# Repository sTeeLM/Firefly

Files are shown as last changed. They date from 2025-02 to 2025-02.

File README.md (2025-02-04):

# 微型长电池寿命多功能户外应急灯

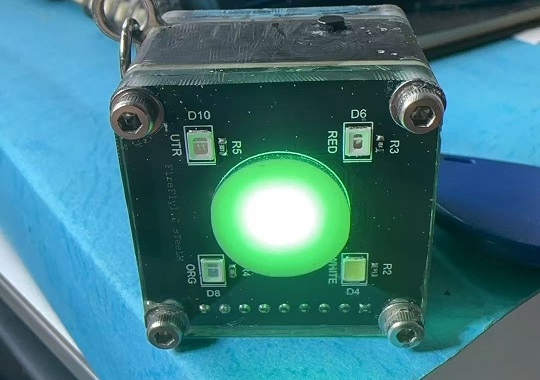
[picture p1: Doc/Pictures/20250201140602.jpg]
前脸
 

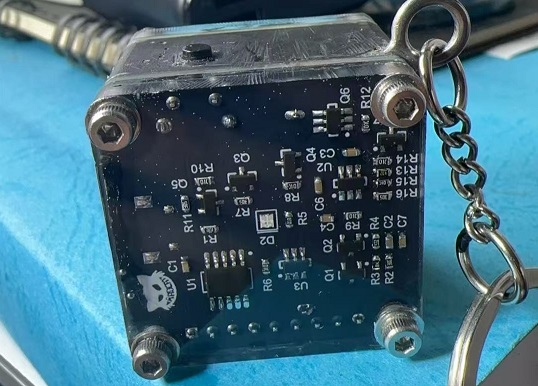
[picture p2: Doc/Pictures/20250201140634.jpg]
后脸


## 有啥用：
   无意间看到淘宝上有类似的户外应急灯，功能比较单一（只有一个荧光灯），还卖的不便宜，正好入手了一些超小号的8引脚单片机，放着也没啥用
   
   平时可以挂在钥匙链上，夜间紧急停车的时候，可以开着频闪放在车后当警示，也能当手电用，登山的时候挂包上，开着荧光节能模式，一闪一闪像萤火虫，可以防止后面队友跟丢（或者是自己丢了方便被找到）。

## 功能：
1. 长电池寿命：长亮模式2小时，5秒频闪模式24小时，长效模式（15秒频闪）3天，关机下漏电nA级别，可长期保存
2. 多种功能：
   * 长效荧光灯:用紫外光周期激发高亮荧光粉，从而以极低的功耗获得不错的照明效果，支持常亮、5秒、15秒三种模式
   * 白光手电：常亮、1秒频闪、5秒频闪三种模式
   * 橙色雾灯：常亮、1秒频闪、5秒频闪三种模式
   * 红色警示灯：常亮、1秒频闪、5秒频闪三种模式
   * 紫外验钞灯：常亮
   * 防误触开机：长按+4次短按开机，误触会有频闪提示，防止装兜里不小心打开
3. 户外设计：
   * 全密封灌胶防尘防水

## 设计细节：
1. 大小35mm x 35mm x 30mm，电池使用LR2447纽扣电池，标称容量190mAh，放电电流100mA，一次只能至多点亮一个LED(60mA)，更多的话需要考虑另一颗电池并联
2. 比较经典的TP4056充电+PW5410B电荷泵升降压到3.3V+USB、电池切换的设计，只是加了一个双MOS管的防止电池向TP4056漏电的设计，从而延长了保存时间
3. 8引脚的STC8G17A单片机+TCA9534A扩展IO，很皮实，而且自带低电压检测功能，国产低端芯片很强大
4. 灌注了两次环氧树脂胶+各种打磨，需要手工比较多，量产的话可以考虑3D打印外壳

# Miniature Multifunctional Outdoor Emergency Light with Long Battery Life
## What It's Used For
I happened to notice some similar outdoor emergency lights on Taobao. They have rather limited functions (only a fluorescent lamp) and are priced quite high. Coincidentally, I had acquired some ultra small 8 pin microcontrollers, which were just sitting idle, so I decided to make one on my own.

Normally, it can be attached to a keychain. In case of an emergency stop at night, it can be turned on with a strobe function and placed behind the car as a warning. It can also serve as a flashlight. When going hiking, hanging it on the backpack and activating the fluorescent energy saving mode, it will flash like a firefly, preventing fellow hikers from losing track of each other (or making it easier for oneself to be located if lost).
## Functions
1. Long Battery Life
* Continuous on mode: 2 hours.
* 5 second strobe mode: 24 hours.
* Extended duration mode (15 second strobe): 3 days.
* Battery leakage is in the nA range when powered off, enabling long term storage.
2. Multiple Functions
* Long lasting Fluorescent Lamp: High brightness phosphors are excited periodically by ultraviolet light, achieving a good lighting effect with extremely low power consumption. It supports three modes: continuous on, 5 second strobe, and 15 second strobe.
* White light Flashlight: Offers three modes: continuous on, 1 second strobe, and 5 second strobe.
* Orange Fog Lamp: Features three modes: continuous on, 1 second strobe, and 5 second strobe.
* Red Warning Light: Has three modes: continuous on, 1 second strobe, and 5 second strobe.
* Anti accidental Startup: It requires a long press followed by four short presses to start. In case of accidental touches, a strobe indication will be given to prevent accidental activation when in the pocket.
3. Outdoor oriented Design
* Fully sealed and potted for dust proof and waterproof performance.
## Design Details
1. The dimensions are 35mm * 35mm * 30mm. It uses an LR2477 button cell battery with a nominal capacity of 190mAh and a discharge current of 100mA. 2. Only one LED (60mA) can be illuminated at a time. If more LEDs need to be lit, parallel connection with another battery should be considered.
2. It adopts a classic design of TP4056 charging, PW5410B charge pump for buck boost to 3.3V, and USB battery switching. Additionally, a dual MOSFET design is added to prevent the battery from leaking current to TP4056, thus prolonging the storage time.
3. An 8 pin STC8G17A microcontroller combined with a TCA9534A for IO expansion is used. These components are robust and come with a built in low voltage detection function. Domestic low end chips prove to be quite powerful.
4. It is potted with epoxy resin glue twice and requires a fair amount of manual work such as various polishing processes. For mass production, a 3D printed shell can be considered.

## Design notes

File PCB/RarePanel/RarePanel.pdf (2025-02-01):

Line # | Name | Description | Designator | Value | Quantity
| | Capacitor | C1 | 104 | 1
| | Capacitor | C2, C7 | 106 | 2
| | Capacitor | C3, C4, C6 | 225 | 3
| 16V | Polarized Capacitor (Radial) | C5 | 100uF | 1
| USB-Micro | USB-Micro | CON1 | | 1
| 1N4148 | Default Diode | D1, D4, D5 | | 3
| RED_GR EEN_LED | RED_GREEN_L ED | D2 | | 1
| 1N4007, T7 | Default Diode | D3 | | 1
| Header 9 | Header, 9-Pin | P1 | | 1
| AO3401, A19T | P-Channel Power MOSFET | Q1, Q3, Q4 | | 3
| S8050,J3 Y | NPN Bipolar Transistor | Q2, Q7 | | 2
| AO3400, A09T | N-Channel Power MOSFET | Q5 | | 1
| AO6801 | AO6801 | Q6 | | 1
| | Resistor | R1 | 300R | 1
| | Resistor | R2 | 20K | 1
| | Resistor | R3, R6, R8, R9, R10, R12, R14, R15 | 10K | 8
| | Resistor | R4, R13 | 4.7K | 2
| | Resistor | R5 | 1K | 1
| | Resistor | R7, R11, R16 | 3M | 3
| Key | Single-Pole, Single-Throw Switch | S1 | | 1
| CH340K | CH340K | U1 | | 1
| PW5410 B | PW5410B | U2 | | 1
| JL4057A | JA4057A | U3 | | 1
| CR2447 | CR2447 | U4 | | 1

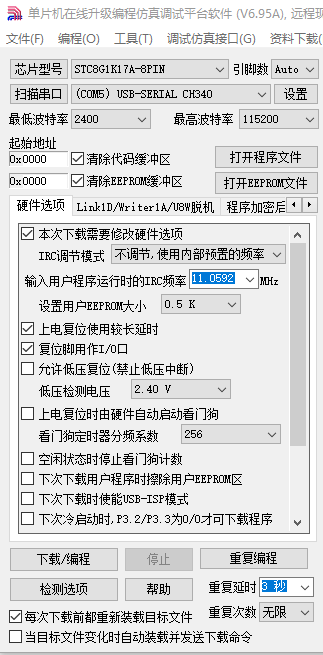
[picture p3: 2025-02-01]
Tools/config.png

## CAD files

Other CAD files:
Shell/A3面板.dwg
Shell/A3背板.dwg

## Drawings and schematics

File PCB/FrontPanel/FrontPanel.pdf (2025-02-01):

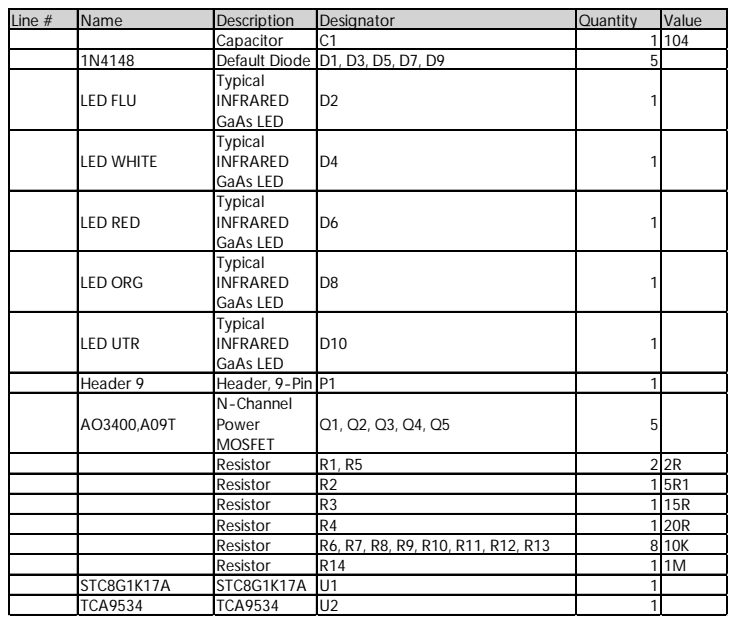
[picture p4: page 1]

Line # | Name | Description | Designator | Quantity | Value

Capacitor | C1 | 1 | 104

1N4148 | Default Diode | D1, D3, D5, D7, D9 | 5
LED FLU | Typical INFRARED GaAs LED | D2 | 1

LED WHITE | Typical INFRARED GaAs LED | D4 | 1

LED RED | Typical INFRARED GaAs LED | D6 | 1

LED ORG | Typical INFRARED GaAs LED | D8 | 1

LED UTR | Typical INFRARED GaAs LED | D10 | 1

Header 9 | Header, 9-Pin | P1 | 1
AO3400,A09T | N-Channel Power MOSFET | Q1, Q2, Q3, Q4, Q5 | 5

Resistor | R1, R5 | 2 2R
Resistor | R2 | 1 | 5R1
Resistor | R3 | 1 | 15R
Resistor | R4 | 1 | 20R
Resistor | R6, R7, R8, R9, R10, R11, R12, R13 | 8 10K
Resistor | R14 | 1 | 1M

STC8G1K17A | STC8G1K17A | U1 | 1
TCA9534 | TCA9534 | U2 | 1

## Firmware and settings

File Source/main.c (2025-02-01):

#include <STC8G.H>

#include "debug.h"
#include "gpio.h"
#include "power.h"
#include "com.h"
#include "delay.h"
#include "task.h"
#include "clock.h"
#include "power.h"
#include "button.h"
#include "int_hub.h"
#include "tdc.h"
#include "led.h"
#include "sm.h"
#include "task.h"

#define START_WAIT_JIFF 8

void main(void)
{
  uint32_t start_jiff;
  uint8_t  button_cnt;
  uint8_t  power_on = 0;
  
  EA = 1; 
  
  debug_initialize();
  gpio_initialize();
  com_initialize();
  power_initialize();
  
  gpio_enable_hub(1);
  
  power_set_enable(1);
  
  //如果插着USB开机，打开串口
  if(power_adapter_on()) {
    gpio_enable_serial(1);
    debug_onoff(1);
  }
  
  int_hub_initilize(); 
 
  clock_initialize();
  button_initialize();
  
  /* 使能其他外设 */
  tdc_initilize();
  led_initialize();
  
  task_initialize();
  sm_initialize(0);
  
  while(key_mod_pressed());
  
  /* 如果没有插充电器，运行防止误触碰逻辑 */
  
  if(!power_adapter_on()) { 
    start_jiff  = clock_get_now_jiff();
    button_cnt = button_get_down_cnt();
    
    while(clock_diff_now_jiff(start_jiff) <= START_WAIT_JIFF) {
      if(task_test(EV_EX_INT)) {
        int_hub_proc(EV_EX_INT);
        task_clr(EV_EX_INT);
      }
      if(button_cnt != button_get_down_cnt()) {
        start_jiff  = clock_get_now_jiff();
        button_cnt = button_get_down_cnt();
      }
      if(button_cnt >= 3) {
        sm_initialize(1);
        break;
      }
    }
  } else {
    CDBG("power_adapter_on\n"); 
  }
  
  led_power_enable(1);
  
  while(1) {
    task_run();
  }
}

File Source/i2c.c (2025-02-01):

#include <intrins.h>
#include <stdint.h>
#include "i2c.h"
#include "debug.h"
#include "delay.h"
#include "gpio.h"



void I2C_Delay()
{
  _nop_();
  _nop_();
  _nop_();
  _nop_();
}

void I2C_Init()
{
 I2C_SCL = 1;
 I2C_Delay();
 I2C_SDA = 1;
 I2C_Delay();
}


void I2C_Start()
{
  I2C_SDA = 1;
  I2C_Delay();
  I2C_SCL = 1;
  I2C_Delay();
  I2C_SDA = 0;
  I2C_Delay();
  I2C_SCL = 0;
  I2C_Delay();
}

void I2C_Stop()
{
  I2C_SDA = 0;
  I2C_Delay();
  I2C_SCL = 1;
  I2C_Delay();
  I2C_SDA = 1;
  I2C_Delay();
  I2C_Delay();
  I2C_Delay();
  I2C_Delay();
	delay_ms(5);
}



void I2C_Write(uint8_t dat)
{

  uint8_t t = 8;
  do
  {
     I2C_SDA = (bit)(dat & 0x80);
     dat <<= 1;
     I2C_SCL = 1;
     I2C_Delay();
     I2C_SCL = 0;
     I2C_Delay();
  } while ( --t != 0 );
}

uint8_t I2C_Read()
{
  char dat = 0;
  uint8_t t = 8;
  I2C_SDA = 1; //在读取数据之前，要把SDA拉高
  do
  {
     I2C_SCL = 1;
     I2C_Delay();
     dat <<= 1;
     if ( I2C_SDA ) dat |= 0x01;
     I2C_SCL = 0;
     I2C_Delay();
  } while ( --t != 0 );
  return dat;
}



bit I2C_GetAck()
{
  bit ack;
  I2C_SDA = 1;
  I2C_Delay();
  I2C_SCL = 1;
  I2C_Delay();
  ack = I2C_SDA;
  I2C_SCL = 0;
  I2C_Delay();
  return ack;
}

void I2C_PutAck(bit ack)
{
  I2C_SDA = ack;
  I2C_Delay();
  I2C_SCL = 1;
  I2C_Delay();
  I2C_SCL = 0;
  I2C_Delay();
}

bit I2C_Puts(uint8_t SlaveAddr, uint8_t SubAddr, uint8_t Size, uint8_t *dat)
{
 if ( Size == 0 ) return 0;

 SlaveAddr &= 0xFE;

 I2C_Start();

 I2C_Write(SlaveAddr);
 if ( I2C_GetAck() )
 {
  I2C_Stop();
  return 1;
 }

 I2C_Write(SubAddr);
 if ( I2C_GetAck() )
 {
  I2C_Stop();
  return 1;
 }

 do
 {
  I2C_Write(*dat++);
  if ( I2C_GetAck() )
  {
   I2C_Stop();
   return 1;
  }
 } while ( --Size != 0 );

 I2C_Stop();
 return 0;
}

bit I2C_Put(uint8_t SlaveAddr, uint8_t SubAddr, char dat)
{
 return I2C_Puts(SlaveAddr,SubAddr,1,&dat);
}


bit I2C_Gets(uint8_t SlaveAddr, uint8_t SubAddr, uint8_t Size, uint8_t *dat)
{
 if ( Size == 0 ) return 0;

 SlaveAddr &= 0xFE; 

 I2C_Start();

 I2C_Write(SlaveAddr);
 if ( I2C_GetAck() )
 {
  I2C_Stop();
  return 1;
 }

 I2C_Write(SubAddr);
 if ( I2C_GetAck() )
 {
  I2C_Stop();
  return 1;
 }

 I2C_Start();

 SlaveAddr |= 0x01;
 I2C_Write(SlaveAddr);
 if ( I2C_GetAck() )
 {
  I2C_Stop();
  return 1;
 }

 for (;;)
 {
  *dat++ = I2C_Read();
  if ( --Size == 0 )
  {
   I2C_PutAck(1);
   break;
  }
  I2C_PutAck(0);
 }

 I2C_Stop();
 return 0;
}

bit I2C_Get(uint8_t SlaveAddr, uint8_t SubAddr, uint8_t *dat)
{
  return I2C_Gets(SlaveAddr, SubAddr, 1,dat);
}
